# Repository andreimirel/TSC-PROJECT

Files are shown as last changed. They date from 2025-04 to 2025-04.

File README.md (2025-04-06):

# OpenBook E-Reader - TSC PROJECT

## General description
  The OpenBook E-Reader is an open-source e-reader device offering a distraction-free reading experience with physical buttons and a minimalist interface. It features environmental sensors that provide real-time environmental data, a sustainable design, and extended battery life of at least one week. The device boasts a large e-paper display, slim ergonomic design, and USB-C connectivity for charging and data transfer. OpenBook supports wireless ebook downloads and emphasizes customizable hardware and software for the tech-savvy reader. It aims to serve avid readers who value open-source technology, customization options, and environmental awareness.

## Block Diagram
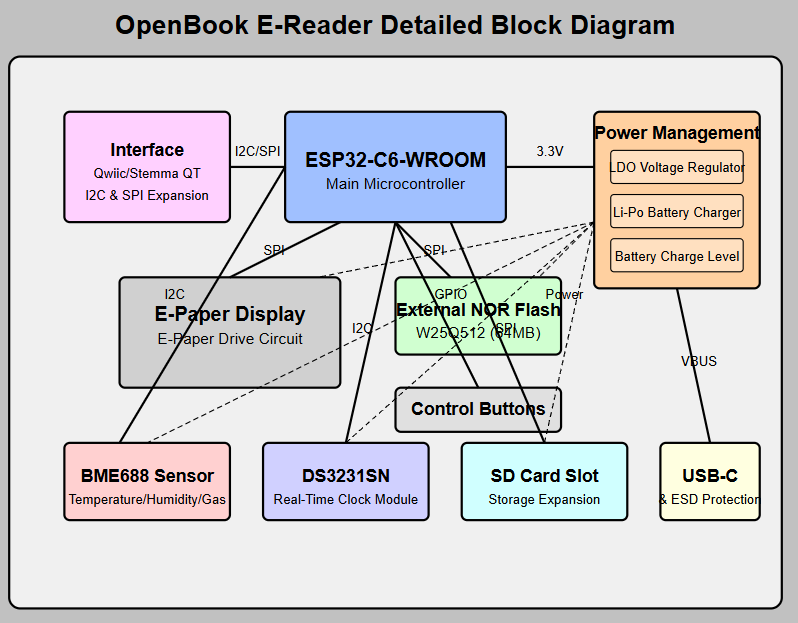
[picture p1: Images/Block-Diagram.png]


## Bill of Materials

| Qty | Value | Description | Manufacturer Part # | Mouser Link |
|-----|---|---|---|---|
| 1 | - | ESP32-C6 Module | ESP32-C6-WROOM-1-N8 | [Datasheet](https://www.mouser.co.uk/datasheet/2/891/Espressif_ESP32_C6_WROOM_1__Datasheet_V0_1_PRELIMI-3239987.pdf) |
| 1 | - | Environmental Sensor | BME688 | [Datasheet](https://www.mouser.co.uk/datasheet/2/783/bst_bme688_fl000-2307034.pdf) |
| 1 | - | Real Time Clock | DS3231SN# | [Datasheet](https://www.mouser.co.uk/datasheet/2/609/DS3231-3421123.pdf) |
| 1 | - | MicroSD Card Socket | 112A-TAAR-R03 ATTEND | [Datasheet](https://www.attend.com.tw/data/download/file/112A-TAAR-R03.rar) |
| 1 | - | USB Type-C Connector | USB4110-GF-A | [Datasheet](https://www.mouser.co.uk/datasheet/2/837/GCT_USB4110_Product_Drawing___20k_cycles-3455479.pdf) |
| 1 | - | FFC Connector | FH34SRJ-24S-0.5SH | [Datasheet](https://www.mouser.co.uk/datasheet/2/185/FH34SRJ_24S_0_5SH_99__CL0580_1255_6_99_2DDrawing_0-1615044.pdf) |
| 1 | - | Qwiic Connector | QWIIC_RIGHT_ANGLE | [Datasheet](https://www.mouser.co.uk/datasheet/2/813/Qwiic_Connector_Datasheet-1223982.pdf) |
| 1 | - | Li-Ion Charge Controller | MCP73831 | [Datasheet](https://www.mouser.co.uk/datasheet/2/268/MCP73831_Family_Data_Sheet_DS20001984H-3441711.pdf) |
| 1 | - | LDO Regulator | XC6220A331MR-G | [Datasheet](https://www.mouser.co.uk/datasheet/2/760/xc6220-3371556.pdf) |
| 1 | - | Fuel Gauge IC | MAX17048G+T10 | [Datasheet](https://www.mouser.co.uk/datasheet/2/609/MAX17048_MAX17049-3469099.pdf) |
| 1 | - | Voltage Detector | BD5229G-TR | [Datasheet](https://fscdn.rohm.com/en/products/databook/datasheet/ic/power/voltage_detector/bd52xxg-e.pdf) |
| 2 | 20V/4.2A | P-Channel MOSFET | DMG2305UX-7 | [Datasheet](https://www.diodes.com/assets/Datasheets/DMG2305UX.pdf) |
| 1 | - | N-Channel MOSFET | SI1308EDL-T1-GE3 | [Datasheet](https://www.vishay.com/doc?63399) |
| 15 | 10kΩ | Resistor | RR0402 | [Datasheet](https://www.mouser.com/ds/2/447/PYu-RC0402_51_RoHS_L_6_r-8721.pdf) |
| 8 | 100nF | Capacitor | CC0402 | [Datasheet](https://eu.mouser.com/datasheet/2/40/cx5r_KGM-3223198.pdf) |
| 10 | 1µF/50V | Capacitor | CC0402 | [Datasheet](https://eu.mouser.com/datasheet/2/40/cx5r_KGM-3223198.pdf) |
| 5 | 4.7µF | Capacitor | CC0402 | [Datasheet](https://eu.mouser.com/datasheet/2/40/cx5r_KGM-3223198.pdf) |
| 3 | - | Schottky Diode | MBR0530 | [Datasheet](https://www.onsemi.com/PowerSolutions/product.do?id=MBR0530T3G) |
| 6 | - | TVS Diode | PGB1010603MR | [Datasheet](https://www.littelfuse.com/assetdocs/pulseguard-esd-suppressors-pgb1-datasheet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) |
| 1 | 100µF | Polarized Capacitor | CPOL-EUCT3528 | [Datasheet](https://www.mouser.co.uk/datasheet/2/396/mlcc02_e-1307760.pdf) |
| 1 | - | Inductor | 744043680 | [Datasheet](https://www.we-online.com/components/products/datasheet/744043680.pdf) |
| 1 | - | ESD Protection Diode | USBLC6-2SC6Y | [Datasheet](https://www.mouser.co.uk/datasheet/2/389/usblc6_2sc6y-1852505.pdf) |
| 2 | - | Schottky Diode | SD0805S020S1R0 | [Datasheet](https://www.mouser.co.uk/datasheet/2/40/schottky-3165252.pdf) |
| 1 | - | Supercapacitor | CPH3225A | [Datasheet](https://www.mouser.co.uk/datasheet/2/360/Seiko_Instruments_MicroBattery_E_20230330_2024Jan_-3561061.pdf) |
| 1 | - | Varistor | ESP32C6_VARISTOR_CT | [Datasheet](https://www.mouser.co.uk/datasheet/2/358/typ_PFMF-1275918.pdf) |
| 17 | - | Test Points | TPTP20R | [Datasheet](https://www.mouser.co.uk/datasheet/2/215/5265_5269-2935484.pdf) |
| 1 | - | Solder Jumper | SJ | [Datasheet](https://www.mouser.co.uk/datasheet/2/210/ASC_WR-3314721.pdf) |
| 1 | - | LED (Green) | ADAFRUIT_LEDCHIP-LED0603 | [Specs](https://www.3dcontentcentral.com/secure/download-model.aspx?catalogid=9481&id=681976) |
| 3 | - | Custom Buttons | BUTTON_CUSYOMV1 | - |

## Core Hardware Modules

### 1. Processing Unit
- **ESP32-C6-WROOM-1-N8**  
  - **Key Features**:
    - 160MHz RISC-V single-core processor
    - 512KB SRAM + 8MB external flash
    - Wi-Fi 6 (802.11ax) and Bluetooth 5 LE
    - Ultra-low-power modes (<5µA deep sleep)
  - **Functions**:
    - Manages all peripheral communication
    - Handles e-book rendering and UI operations
    - Processes environmental sensor data
    - Manages power states and battery charging

### 2. Display System
- **7.5" E-Paper Display (WSH-13187)**
  - **Specifications**:
    - 800×480 resolution, 8:1 contrast ratio
    - SPI interface (4-wire) @ 10MHz max
    - Partial refresh (<0.5s), full refresh (<1s)
    - 170° viewing angle
  - **Power Management**:
    - 0W power consumption when static
    - 120mW during refresh (active)

### 3. Environmental Sensing
- **BME688 Integrated Sensor**
  - **Measurement Capabilities**:
    - Temperature: ±1°C accuracy (0-65°C)
    - Humidity: ±3% RH (20-80% RH)
    - Pressure: ±1 hPa (300-1100 hPa)
    - Air Quality: VOC and eCO2 detection
  - **Interface**:
    - I2C @ 400kHz
    - 30s warm-up time for accurate readings
  - **Power Consumption**:
    - 2mA during active measurement
    - 0.5µA in sleep mode

### 4. Power Management System
| Component | Function | Specifications |
|---|---|---|
| **2500mAh LiPo Battery** | Primary power source | 3.7V nominal, 2C discharge rate |
| **MCP73831** | Battery charging | 500mA max charge current, 4.2V regulation |
| **MAX17048** | Fuel gauge | ±1% voltage accuracy, I2C interface |
| **XC6220A331MR-G** | Voltage regulator | 3.3V @ 300mA, 50µA quiescent current |

### 5. User Interface Components
- **Tactile Buttons (3x)**
  - Panasonic EVQ-Q2A03W switches
  - 1M cycle lifespan
  - Hardware-debounced (RC filters)
- **LED Indicators**:
  - Charging status (red/green)
  - System activity (blue)

### 6. Connectivity
- **USB-C Port (Amphenol 12401641E4R)**
  - USB 2.0 Full Speed (12Mbps)
  - 5V/1A charging
  - ESD protection (USBLC6-2SC6Y)
- **Wi-Fi 6**:
  - 20MHz channel bandwidth
  - WPA3 security support
  - OTA update capability

### 7. Memory & Storage
| Component | Type | Capacity | Interface |
|---|---|---|---|
| **W25Q512JVEIQ** | SPI Flash | 512Mb (64MB) | Quad-SPI @ 133MHz |
| **MicroSD Slot** | Expandable | Up to 1TB | SPI @ 25MHz |

## ESP32-C6 Pins

| ESP32-C6 Pin | Component / Function  | Description and Reason for Use |
|---|---|---|
| IO1 (SDA) | I2C Bus | Used for communication with the BME688 sensor, battery fuel gauge IC (MAX17048), and RTC (DS3231). I²C enables multiple devices on one bus. |
| IO2 (SCL) | I2C Clock | Provides the clock signal for the I²C bus, synchronizing data transfer between the ESP32-C6 and connected I²C devices. |
| IO5 (MISO) | SPI (E-Paper) | Master In Slave Out for the SPI interface with the E-Paper display; receives data from the display to the ESP32-C6. |
| IO6 (MOSI) | SPI (E-Paper) | Master Out Slave In for the SPI interface with the E-Paper display; sends data from the ESP32-C6 to the display. |
| IO7 (SCK) | SPI Clock (E-Paper) | Provides the clock signal for the SPI interface with the E-Paper display, synchronizing data transfer. |
| IO8 (CS) | Chip Select (E-Paper) | Selects the E-Paper display for SPI communication, allowing communication with a single SPI device at a time. |
| IO9 | E-Paper DC | Data/Command control for the E-Paper display, indicating whether the transmitted data is command instructions or display data. |
| IO10 | E-Paper RST | Reset pin for the E-Paper display, used to initialize or reset the display. |
| IO11 | E-Paper BUSY | Busy status pin for the E-Paper display, indicating if the display is occupied and cannot receive new commands. |
| IO12 | BUTTON_BOOT | Button to enter programming/bootload mode. |
| IO13 | BUTTON_RESET | Button for hardware reset of the ESP32-C6. |
| IO14 | BUTTON_USER | User-defined button for application interactions. |
| IO15 | MAX17048 ALERT | Alert pin from the battery fuel gauge IC, signaling critical battery conditions. |
| GPIO16/TXD0 | USB D+ | Positive data line for the USB interface. |
| GPIO17/RXD0 | USB D- | Negative data line for the USB interface. |
| IO18 | STATUS_LED | Controls the status LED for visual indication of the device state. |
| IO19 | SD Card CS | Chip select for the SD card on the SPI interface. |
| IO20 | SD Card MISO | Master In Slave Out for the SPI interface with the SD card; receives data from the SD card. |
| IO21 | SD Card MOSI | Master Out Slave In for the SPI interface with the SD card; sends data to the SD card. |
| IO4 | SD Card CLK | SPI clock for the SD card, synchronizing data transfer. |

###  Additional Details - ESP32-C6 Pins
  
  ####   I2C Interface
      The GPIO1 (SDA) and GPIO2 (SCL) pins are used for the I²C bus, connecting the ESP32-C6 to:
        - **BME688 Sensor:** For reading temperature, humidity, pressure, and air quality data.
        - **MAX17048:** For monitoring battery level.
        - **DS3231:** For real-time clock (RTC) functionality.
    
  ####   SPI Interface
      The GPIO5, GPIO6, GPIO7, and GPIO8 pins are dedicated to the SPI interface with the E-Paper display. This interface requires:
        - **MISO (GPIO5):** Receives data from the display.
        - **MOSI (GPIO6):** Transmits data to the display.
        - **SCK (GPIO7):** Synchronizes the data transfer.
        - **CS (GPIO8):** Selects the E-Paper display for communication.
    
  ####  User Buttons
      The GPIO12, GPIO13, and GPIO14 pins are connected to the user control buttons:
        - **GPIO12 (BUTTON_BOOT):** Enters programming/bootload mode.
        - **GPIO13 (BUTTON_RESET):** Resets the ESP32-C6.
        - **GPIO14 (BUTTON_USER):** Allows user-defined interactions.
    
  ####  USB
      GPIO16 and GPIO17 are used for the USB interface, facilitating data transfer and charging.
    
  ####  SD Card
      The GPIO19, GPIO20, GPIO21, and GPIO4 pins are used for the SPI interface with the SD card, enabling data storage and access.

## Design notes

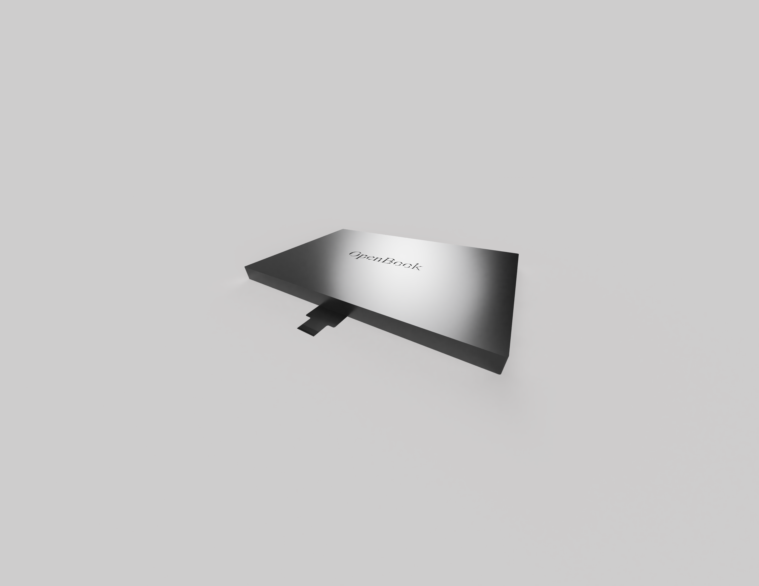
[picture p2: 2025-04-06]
Images/OpenBook_E-Book_Reader_2025-Apr-06_10-16-19AM-000_CustomizedView25883885497_png.png

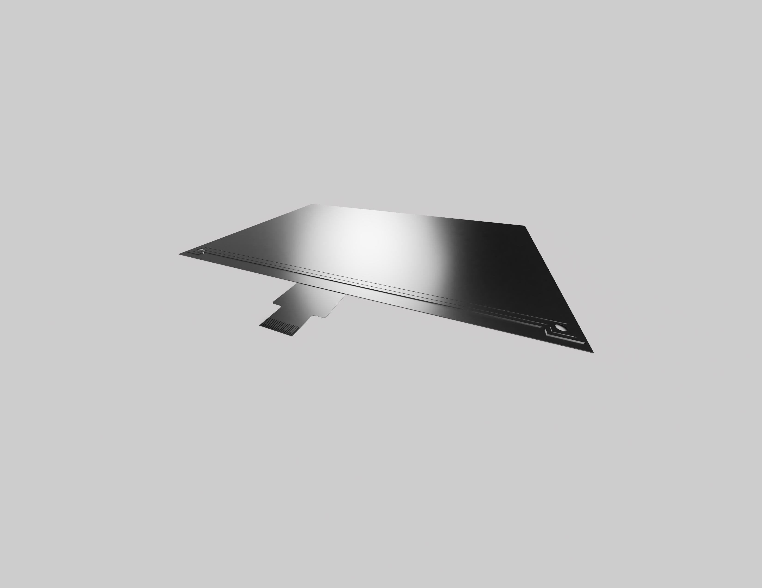
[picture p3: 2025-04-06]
Images/OpenBook_E-Book_Reader_2025-Apr-06_10-19-33AM-000_CustomizedView18438601844_png.png

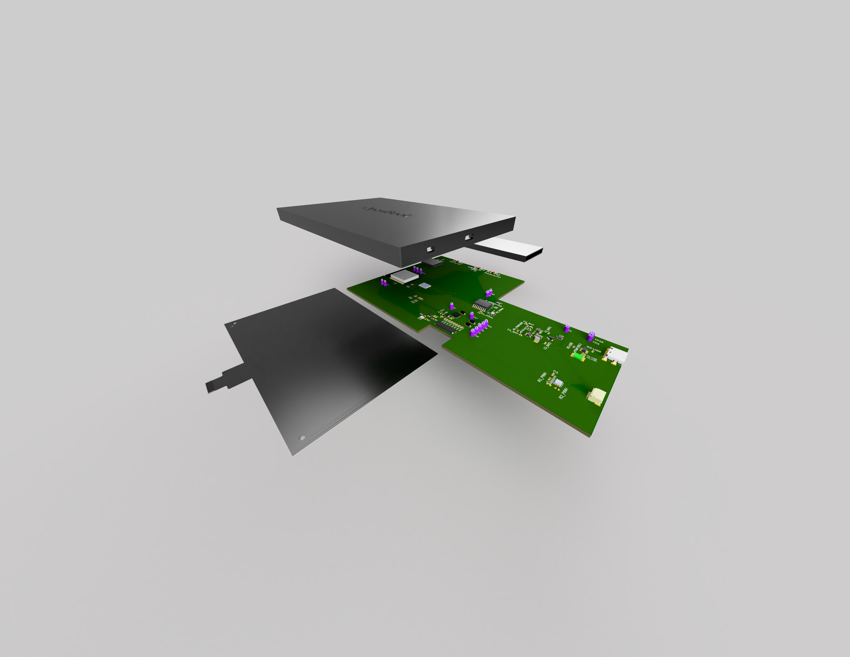
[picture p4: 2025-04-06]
Images/OpenBook_E-Book_Reader_2025-Apr-06_10-23-46AM-000_CustomizedView27298161075_png.png

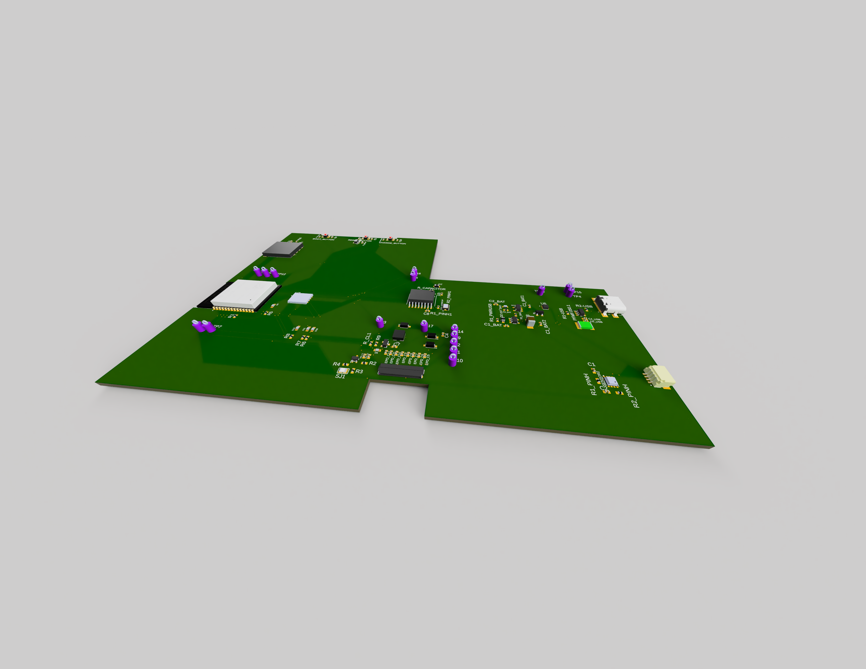
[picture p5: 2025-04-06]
Images/OpenBook_E-Book_Reader_2025-Apr-06_10-17-53AM-000_CustomizedView38768882471_png.png

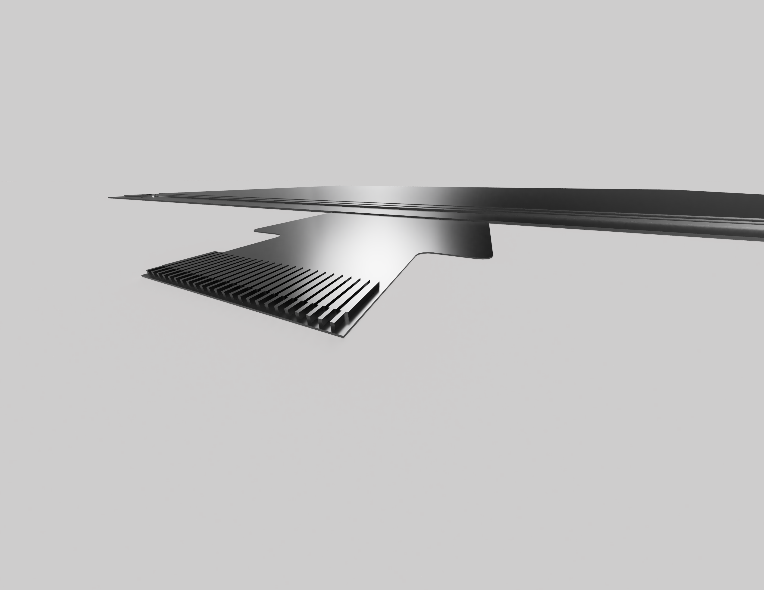
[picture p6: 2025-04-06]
Images/OpenBook_E-Book_Reader_2025-Apr-06_10-20-03AM-000_CustomizedView36715459351_png.png

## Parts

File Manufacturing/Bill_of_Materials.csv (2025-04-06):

Qty | Value | Device | Package | Parts | Description | ARROW_PART_NUMBER | ARROW_PRICE-STOCK | AVAILABILITY | CENTROID_NOT_SPECIFIED | CHECK_PRICES | COPYRIGHT | DATASHEET | DESCRIPTION | DIGIKEY_DESCRIPTION | DIGIKEY_PART_NUMBER | HEIGHT | LEAD_FREE | MANUFACTURER_NAME | MANUFACTURER_PART_NUMBER | MF | MFR_NAME | MOUSER_PART_NUMBER | MOUSER_PRICE-STOCK | MOUSER_TESTING_PART_NUMBER | MOUSER_TESTING_PRICE-STOCK | MP | MPN | PACKAGE | POPULARITY | PREFIX | PRICE | PROD_ID | PURCHASE-URL | ROHS | SNAPEDA_LINK | SPICEMODEL | SPICEPREFIX | TEMPERATURE_RANGE_HIGH | TEMPERATURE_RANGE_LOW | TP_SIGNAL_NAME | VALUE
1 |  | ADAFRUIT_LEDCHIP-LED0603 | ADAFRUIT_CHIP-LED0603 | CHG_LED | LED
3 |  | BUTTON_CUSYOMV1 | MYBUTTON | BOOT_BUTTON, CHANGE_BUTTON, RESET_BUTTON
1 |  | ESP32C6_VARISTORCN1812 | ESP32C6_VARISTOR_CT/CN1812 | PFMF.050.1 | VARISTOR |  |  |  |  |  |  |  |  |  |  |  |  |  |  |  |  |  |  |  |  |  |  |  | 0
1 |  | ESP32_WROVER_SPARKFUN-IC-POWER_MCP73831 | ESP32_WROVER_SPARKFUN-IC-POWER_SOT23-5 | MCP73831 | MCP73831T Li-Ion, Li-Pol Controller |  |  |  |  |  |  |  |  |  |  |  |  |  |  |  |  |  |  |  |  |  |  |  |  |  |  | IC-09995
1 |  | SAMACSYS_PARTS_USB4110-GF-A | SAMACSYS_PARTS_USB4110GFA | J2 | CONN USB 2.0 TYPE-C R/A SMT |  |  |  |  |  |  |  | CONN USB 2.0 TYPE-C R/A SMT |  |  | 3.26mm |  | GCT (GLOBAL CONNECTOR TECHNOLOGY) | USB4110-GF-A |  |  | 640-USB4110-GF-A | https://www.mouser.co.uk/ProductDetail/GCT/USB4110-GF-A?qs=KUoIvG%2F9IlYiZvIXQjyJeA%3D%3D
1 |  | SJ | SJ | SJ1 | SMD solder JUMPER |  |  |  |  |  |  |  |  |  |  |  |  |  |  |  |  |  |  |  |  |  |  |  | 3
1 | 0.47 | ESP32_WROVER_EAGLE-LTSPICE_RR0402 | ESP32_WROVER_EAGLE-LTSPICE_R0402 | R3 | RESISTOR, European symbol |  |  |  |  |  |  |  |  |  |  |  |  |  |  |  |  |  |  |  |  |  |  |  |  |  |  |  |  |  |  | NONE | R
1 | 100k | ESP32_WROVER_EAGLE-LTSPICE_RR0402 | ESP32_WROVER_EAGLE-LTSPICE_R0402 | R1_PWRUSB | RESISTOR, European symbol |  |  |  |  |  |  |  |  |  |  |  |  |  |  |  |  |  |  |  |  |  |  |  |  |  |  |  |  |  |  | NONE | R
8 | 100nF | EAGLE-LTSPICE_CC0402 | EAGLE-LTSPICE_C0402 | C1, C2, C4_USB, C6, C8, C9, C10\, C_DELAY | CAPACITOR, European symbol |  |  |  |  |  |  |  |  |  |  |  |  |  |  |  |  |  |  |  |  |  |  |  |  |  |  |  |  |  |  | NONE | C
1 | 100uF | RCL_CPOL-EUCT3528 | RCL_CT3528 | C3 | POLARIZED CAPACITOR, European symbol |  |  |  |  |  |  |  |  |  |  |  |  |  |  |  |  |  |  |  |  |  |  |  | 0 |  |  |  |  |  |  |  | C
15 | 10K | ESP32_WROVER_EAGLE-LTSPICE_RR0402 | ESP32_WROVER_EAGLE-LTSPICE_R0402 | R1, R1_PINH, R1_PINH1, R2_PINH, R2_PINH1, R5, R6, R7, R8, R9, R10, R_BUTTON, R_CHANGE, R_CL1, R_RESET | RESISTOR, European symbol |  |  |  |  |  |  |  |  |  |  |  |  |  |  |  |  |  |  |  |  |  |  |  |  |  |  |  |  |  |  | NONE | R
1 | 10k | ESP32_WROVER_EAGLE-LTSPICE_RR0402 | ESP32_WROVER_EAGLE-LTSPICE_R0402 | R4 | RESISTOR, European symbol |  |  |  |  |  |  |  |  |  |  |  |  |  |  |  |  |  |  |  |  |  |  |  |  |  |  |  |  |  |  | NONE | R
1 | 10uF | EAGLE-LTSPICE_CC0402 | EAGLE-LTSPICE_C0402 | C7 | CAPACITOR, European symbol |  |  |  |  |  |  |  |  |  |  |  |  |  |  |  |  |  |  |  |  |  |  |  |  |  |  |  |  |  |  | NONE | C
1 | 112A-TAAR-R03_ATTEND | 112A-TAAR-R03_ATTEND | 112ATAARR03ATTEND | U2 | Micro SD Card Socket, Push-Push Type, Top Mount, SMT, H=1.83mm, 10u |  |  |  |  |  |  |  | Micro SD Card Socket | Push-Push Type | Top Mount | SMT | H=1.83mm | 10u |  |  | 1.9mm |  | ATTEND | 112A-TAAR-R03 ATTEND
1 | 15 | ESP32_WROVER_EAGLE-LTSPICE_RR0402 | ESP32_WROVER_EAGLE-LTSPICE_R0402 | R_CAPACITOR | RESISTOR, European symbol |  |  |  |  |  |  |  |  |  |  |  |  |  |  |  |  |  |  |  |  |  |  |  |  |  |  |  |  |  |  | NONE | R
1 | 1uF | EAGLE-LTSPICE_CC0402 | EAGLE-LTSPICE_C0402 | C5 | CAPACITOR, European symbol |  |  |  |  |  |  |  |  |  |  |  |  |  |  |  |  |  |  |  |  |  |  |  |  |  |  |  |  |  |  | NONE | C
10 | 1uF/50V | EAGLE-LTSPICE_CC0402 | EAGLE-LTSPICE_C0402 | EPD_C1, EPD_C2, EPD_C5, EPD_C6, EPD_C7, EPD_C8, EPD_C9, EPD_C10, EPD_C11, EPD_C12 | CAPACITOR, European symbol |  |  |  |  |  |  |  |  |  |  |  |  |  |  |  |  |  |  |  |  |  |  |  |  |  |  |  |  |  |  | NONE | C
1 | 2.2 | ESP32_WROVER_EAGLE-LTSPICE_RR0402 | ESP32_WROVER_EAGLE-LTSPICE_R0402 | R2 | RESISTOR, European symbol |  |  |  |  |  |  |  |  |  |  |  |  |  |  |  |  |  |  |  |  |  |  |  |  |  |  |  |  |  |  | NONE | R
1 | 200 | ESP32_WROVER_EAGLE-LTSPICE_RR0402 | ESP32_WROVER_EAGLE-LTSPICE_R0402 | R1_BAT | RESISTOR, European symbol |  |  |  |  |  |  |  |  |  |  |  |  |  |  |  |  |  |  |  |  |  |  |  |  |  |  |  |  |  |  | NONE | R
2 | 20V/4.2A/52mΩ/1.4W | ESP32_WROVER_SPARKFUN-DISCRETESEMI_MOSFET_PCH-DMG2305UX-7 | ESP32_WROVER_SPARKFUN-DISCRETESEMI_SOT23-3 | Q1, Q2 | P-channel MOSFETs |  |  |  |  |  |  |  |  |  |  |  |  |  |  |  |  |  |  |  |  |  |  |  |  |  |  | TRAN-14388 |  |  |  |  |  |  |  |  | 20V/4.2A/52mΩ/1.4W
1 | 2K | ESP32_WROVER_EAGLE-LTSPICE_RR0402 | ESP32_WROVER_EAGLE-LTSPICE_R0402 | R2_BAT | RESISTOR, European symbol |  |  |  |  |  |  |  |  |  |  |  |  |  |  |  |  |  |  |  |  |  |  |  |  |  |  |  |  |  |  | NONE | R
5 | 4.7uF | EAGLE-LTSPICE_CC0402 | EAGLE-LTSPICE_C0402 | C1_BAT, C1_BAT1, C1_BAT2, C2_BAT, C5_USB | CAPACITOR, European symbol |  |  |  |  |  |  |  |  |  |  |  |  |  |  |  |  |  |  |  |  |  |  |  |  |  |  |  |  |  |  | NONE | C
1 | 4.7uF/25V | EAGLE-LTSPICE_CC0402 | EAGLE-LTSPICE_C0402 | C4 | CAPACITOR, European symbol |  |  |  |  |  |  |  |  |  |  |  |  |  |  |  |  |  |  |  |  |  |  |  |  |  |  |  |  |  |  | NONE | C
2 | 5k1 | ESP32_WROVER_EAGLE-LTSPICE_RR0402 | ESP32_WROVER_EAGLE-LTSPICE_R0402 | R1-USB, R2-USB | RESISTOR, European symbol |  |  |  |  |  |  |  |  |  |  |  |  |  |  |  |  |  |  |  |  |  |  |  |  |  |  |  |  |  |  | NONE | R
1 | 744043680IND_4828-WE-TPC_WRE | 744043680IND_4828-WE-TPC_WRE | IND_4828-WE-TPC_WRE | L1 |  |  |  |  |  |  | Copyright (C) 2024 Ultra Librarian. All rights reserved. |  |  |  |  |  |  |  | 744043680 |  | Wurth Electronics
1 | BD5229G-TR | BD5229G-TR | SOT95P280X125-5N | IC1 | Voltage Detector with Adjustable Delay Time: CMOS processes are utilized to develop high precision, low current consumption CMOS reset ICs that allow arbitrary setting of the delay time. The extensive lineup includes both Nch Open Drain and CMOS output types in a wide range of detection voltages (from 2.3V to 6.0V, in 0.1V steps), enabling selection of the ideal solution based on customer requirements. In addition, the entire series is of course both lead-free and RoHS-compliant. |  |  |  |  |  |  |  | Voltage Detector with Adjustable Delay Time: CMOS processes are utilized to develop high precision | low current consumption CMOS reset ICs that allow arbitrary setting of the delay time. The extensive lineup includes both Nch Open Drain and CMOS output types in a wide range of detection voltages (from 2.3V to 6.0V | in 0.1V steps) | enabling selection of the ideal solution based on customer requirements. In addition | the entire series is of course both lead-free and RoHS-compliant. |  |  | 1.25mm |  | ROHM Semiconductor | BD5229G-TR |  |  | 755-BD5229G-TR | https://www.mouser.co.uk/ProductDetail/ROHM-Semiconductor/BD5229G-TR?qs=4kLU8WoGk0vvnhrrYwdszw%3D%3D
1 | BME688 | ESP32_WROVER_BME680_BME680 | ESP32_WROVER_BME680_PSON80P300X300X100-8N | SENSOR2 | Integrated Environmental Unit |  |  | Unavailable |  |  |  |  | Integrated Environmental Unit |  |  |  |  |  |  | Bosch Sensortec |  |  |  |  |  | BME680 |  | LGA-8 Bosch Tools |  |  | None
1 | CPH3225A | CPH3225A | CAPCP3225X100N | C10_SUPERCAP | Cap 0.011F 3.3V 1210 Flat Check availability |  |  | Not in stock |  | https://www.snapeda.com/parts/CPH3225A/Seiko+Instruments/view-part/?ref=eda |  |  | 11 mF (EDLC) Supercapacitor 3.3 V 1210 (3225 Metric) - - |  |  |  |  |  |  | Seiko Instruments |  |  |  |  |  | CPH3225A |  | 1210 Seiko |  |  | None |  | https://www.snapeda.com/api/url_track_click_mouser/?unipart_id=562593&manufacturer=Seiko Instruments&part_name=CPH3225A&search_term=None |  | https://www.snapeda.com/parts/CPH3225A/Seiko+Instruments/view-part/?ref=snap
1 | DS3231SN# | DS3231SN# | SOIC127P1032X265-16N | U3 | Real Time Clock Serial 16-Pin SOIC W T/R Check availability |  |  | In Stock |  | https://www.snapeda.com/parts/DS3231SN%23/Analog+Devices/view-part/?ref=eda |  |  | Extremely Accurate I²C-Integrated RTC/TCXO/Crystal |  |  |  |  |  |  | Analog Devices |  |  |  |  |  | DS3231SN# |  | SOIC-16 Maxim |  |  | None |  | https://www.snapeda.com/api/url_track_click_mouser/?unipart_id=99048&manufacturer=Analog Devices&part_name=DS3231SN#&search_term=None |  | https://www.snapeda.com/parts/DS3231SN%23/Analog+Devices/view-part/?ref=snap
1 | ESP32-C6-WROOM-1-N8 | ESP32-C6-WROOM-1-N8 | XCVR_ESP32-C6-WROOM-1-N8 | U1 | Check availability |  |  | In Stock |  | https://www.snapeda.com/parts/ESP32-C6-WROOM-1-N8/Espressif+Systems/view-part/?ref=eda |  |  | Multiprotocol Modules ESP32-C6 module | Wi-Fi 6 in 2.4 GHz band | Bluetooth 5 | Zigbee 3.0 and Thread. ESP34-WROOM Compatible - ENGINEERING SAMPLE |  |  |  |  |  |  | Espressif Systems |  |  |  |  |  | ESP32-C6-WROOM-1-N8 |  | None |  |  | None |  |  |  | https://www.snapeda.com/parts/ESP32-C6-WROOM-1-N8/Espressif+Systems/view-part/?ref=snap
2 | ESP32_WROVER_AVX---SD0805S020S1R0_AVX_SD0805S020S1R0_0_0AVX_SD0805S020S1R0_0_0 | ESP32_WROVER_AVX---SD0805S020S1R0_AVX_SD0805S020S1R0_0_0AVX_SD0805S020S1R0_0_0 | ESP32_WROVER_AVX---SD0805S020S1R0_AVX_SD0805S020S1R0_0 | D2, D7 | Schottky Barrier Rectifier Diode |  |  |  | No |  |  | http://datasheets.avx.com/schottky.pdf |  | DIODE SCHOTTKY 20V 1A 0805 | 478-7800-1-ND |  | yes |  |  | AVX |  | 581-SD0805S020S1R0 |  |  |  |  |  | 0805 (2012 metric) |  | D |  |  |  | yes |  |  |  | +125°C | -55°C
1 | FH34SRJ-24S-0.5SH_99_ | FH34SRJ-24S-0.5SH_99_ | FH34SRJ24S05SH99 | J1 | (0.50mm) Surface Mount, Right Angle |  |  |  |  |  |  |  | 24 Position FFC | FPC Connector Contacts | (0.50mm) Surface Mount | Right Angle |  |  | 1.1mm |  | Hirose | FH34SRJ-24S-0.5SH(99) |  |  | 798-FH34SRJ24S05SH99 | https://www.mouser.co.uk/ProductDetail/Hirose-Connector/FH34SRJ-24S-0.5SH99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
1 | MAX17048G+T10 | MAX17048G+T10 | SON50P200X200X80-9N | U5 | Check availability |  |  | In Stock |  | https://www.snapeda.com/parts/MAX17048G+T10/Analog+Devices/view-part/?ref=eda |  |  | 3µA 1-Cell/2-Cell Fuel Gauge with ModelGauge |  |  |  |  |  |  | Analog Devices |  |  |  |  |  | MAX17048G+T10 |  | TDFN-8 Maxim |  |  | None |  | https://www.snapeda.com/api/url_track_click_mouser/?unipart_id=329239&manufacturer=Analog Devices&part_name=MAX17048G+T10&search_term=None |  | https://www.snapeda.com/parts/MAX17048G+T10/Analog+Devices/view-part/?ref=snap
3 | MBR0530 | MBR0530 | SOD3716X135N | D3, D4, D5 | ON SEMICONDUCTOR - MBR0530 - DIODE, SCHOTTKY, 0.5A, 30V, SOD-123 |  |  | In Stock |  | https://www.snapeda.com/parts/MBR0530/Onsemi/view-part/?ref=eda |  |  | Diode Schottky 30 V 500mA Surface Mount SOD-123 |  |  |  |  |  |  | ON Semiconductor |  |  |  |  |  | MBR0530 |  | SOD-123-2 ON Semiconductor |  |  | None |  | https://www.snapeda.com/api/url_track_click_mouser/?unipart_id=179458&manufacturer=ON Semiconductor&part_name=MBR0530&search_term=None |  | https://www.snapeda.com/parts/MBR0530/Onsemi/view-part/?ref=snap
6 | PGB1010603MR | PGB1010603MR | DIOC1608X36N | D6, D8, D9, D10, D11, D12 | Check availability |  |  | In Stock |  | https://www.snapeda.com/parts/PGB1010603MR/Littelfuse/view-part/?ref=eda |  |  | 150V (Typ) Clamp - Ipp Tvs Diode Surface Mount 0603 (1608 Metric) |  |  |  |  |  |  | Littelfuse Inc. |  |  |  |  |  | PGB1010603MR |  | 0603 Littelfuse Inc. |  |  | None |  | https://www.snapeda.com/api/url_track_click_mouser/?unipart_id=5659453&manufacturer=Littelfuse Inc.&part_name=PGB1010603MR&search_term=None |  | https://www.snapeda.com/parts/PGB1010603MR/Littelfuse/view-part/?ref=snap
1 | QWIIC_RIGHT_ANGLE | QWIIC_CONNECTORJS-1MM | JST04_1MM_RA | J3 | SparkFun I2C Standard Qwiic Connector |  |  |  |  |  |  |  |  |  |  |  |  |  |  |  |  |  |  |  |  |  |  |  |  |  |  | CONN-13694 |  |  |  |  |  |  |  |  | QWIIC_RIGHT_ANGLE
1 | SI1308EDL-T1-GE3 | SI1308EDL-T1-GE3 | SOT65P210X110-3N | Q3 | MOSFET N-Ch 30V 1.5A TrenchFET SC70 Vishay Si1308EDL-T1-GE3 N-channel MOSFET Transistor, 1.5 A, 30 V, 3-Pin SC-70 |  |  | In Stock |  | https://www.snapeda.com/parts/SI1308EDL-T1-GE3/Vishay+Siliconix/view-part/?ref=eda |  |  | Si1308EDL-T1-GE3 N-channel MOSFET Transistor | 1.5 A | 30 V | 3-Pin SC-70 | Siliconix / Vishay SI1308EDL-T1-GE3 |  |  |  |  |  |  | Vishay Siliconix |  |  |  |  |  | SI1308EDL-T1-GE3 |  | SOT-323 Vishay Semiconductor |  |  | None |  | https://www.snapeda.com/api/url_track_click_mouser/?unipart_id=274603&manufacturer=Vishay Siliconix&part_name=SI1308EDL-T1-GE3&search_term=None |  | https://www.snapeda.com/parts/SI1308EDL-T1-GE3/Vishay+Siliconix/view-part/?ref=snap
17 | TPTP20R | TPTP20R | TP20R | TP1, TP2, TP3, TP4, TP5, TP6, TP7, TP8, TP9, TP10, TP11, TP12, TP13, TP14, TP15, TP16, TP17 | Test pad |  |  |  |  |  |  |  |  |  |  |  |  |  |  |  |  |  |  |  |  |  |  |  | 2
1 | USBLC6-2SC6Y | USBLC6-2SC6Y | SOT95P280X145-6N | D1 | Low Cap. ESD Protection Auto SOT-23-6 STMicroelectronics USBLC6-2SC6Y, Dual Uni-Directional TVS Diode Array, 6-Pin SOT-23 |  |  | In Stock |  | https://www.snapeda.com/parts/USBLC6-2SC6Y/STMicroelectronics/view-part/?ref=eda |  |  | 17V Clamp 5A (8/20µs) Ipp Tvs Diode Surface Mount SOT-23-6 |  |  |  |  |  |  | STMicroelectronics |  |  |  |  |  | USBLC6-2SC6Y |  | SOT-23-6 STMicroelectronics |  |  | None |  |  |  | https://www.snapeda.com/parts/USBLC6-2SC6Y/STMicroelectronics/view-part/?ref=snap
1 | W25Q512JVEIQ | W25Q512JVEIQ | SON127P600X800X80-9N | U7 | Check availability |  |  | In Stock |  | https://www.snapeda.com/parts/W25Q512JVEIQ/Winbond+Electronics/view-part/?ref=eda |  |  | FLASH - NOR Memory IC 512Mb (64M x 8) SPI - Quad I/O 133 MHz 8-WSON (8x6) |  |  |  |  |  |  | Winbond Electronics |  |  |  |  |  | W25Q512JVEIQ |  | Package |  |  | None |  |  |  | https://www.snapeda.com/parts/W25Q512JVEIQ/Winbond+Electronics/view-part/?ref=snap
1 | XC6220A331MR-G | XC6220A331MR-G | SOT95P280X120-5N | IC2 | LDO Voltage Regulators |  |  |  |  |  |  |  | LDO Voltage Regulators |  |  | 1.2mm |  | Torex | XC6220A331MR-G |  |  | 865-XC6220A331MR-G | https://www.mouser.co.uk/ProductDetail/Torex-Semiconductor/XC6220A331MR-G?qs=AsjdqWjXhJ8ZSWznL1J0gg%3D%3D

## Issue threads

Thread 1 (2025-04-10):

Schematic review

PXrotters, 2025-04-10:
## ERC Check:

✔️ **ERC check performed:** All reported issues are either tool quirks or false positives.

---

## Component Issues:

- **Missing values on components** (e.g., CHG_LED, SJ1, FRAME1): These appear intentional but could benefit from further clarification in the BOM.
- **POWER pins connected to non-default rails** (e.g., VDD to VBAT, VCC to 3V3): Cross-checked with datasheets and confirmed to be correct.

---

## Pin Verification:

✔️ **Pins verified and match datasheets.**
- Some component signal names differ slightly from the reference schematic, but they map correctly to the expected pins and behavior. These inconsistencies do not affect functionality but could be aligned in future versions for consistency.

---

## Component Footprints:

✔️ **Verified component footprints** — schematic symbol matches actual PCB package and pin count. All match datasheets.

---

Passive Components, Power Supply, Regulators, Decoupling, Errata, Signals, Analog, Clocks, Strap/init pins, External Interface Protection, Debugging / Reworkability, Thermal: all are ok and perform as expected.

## General Status:

**Passive Components, Power Supply, Regulators, Decoupling, Errata, Signals, Analog, Clocks, Strap/init pins, External Interface Protection, Debugging / Reworkability, Thermal:** All are **OK** and perform as expected.

**Suggested labels:** `documentation`, `enhancement`

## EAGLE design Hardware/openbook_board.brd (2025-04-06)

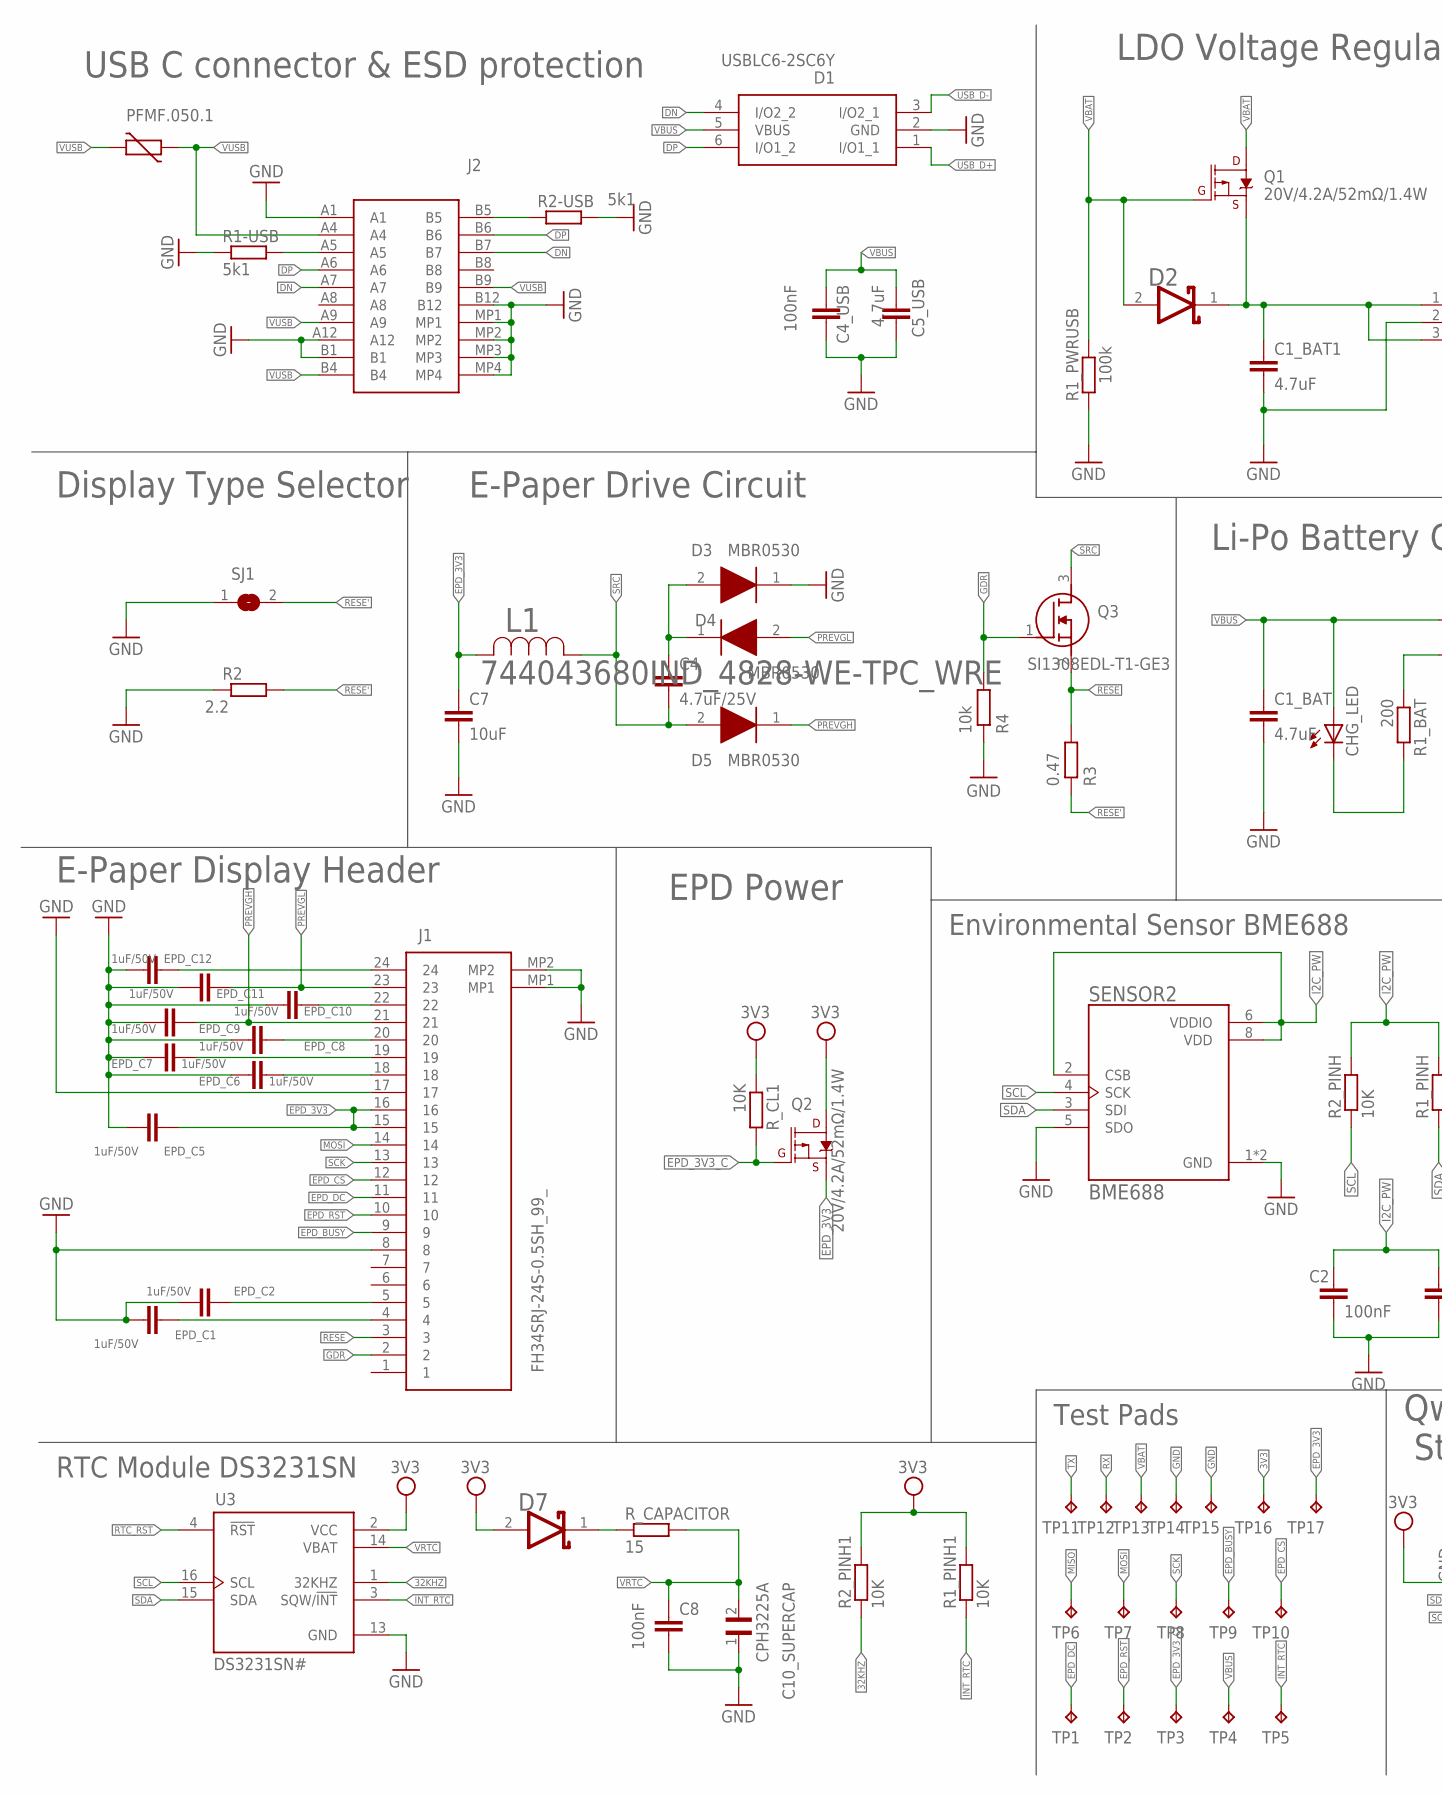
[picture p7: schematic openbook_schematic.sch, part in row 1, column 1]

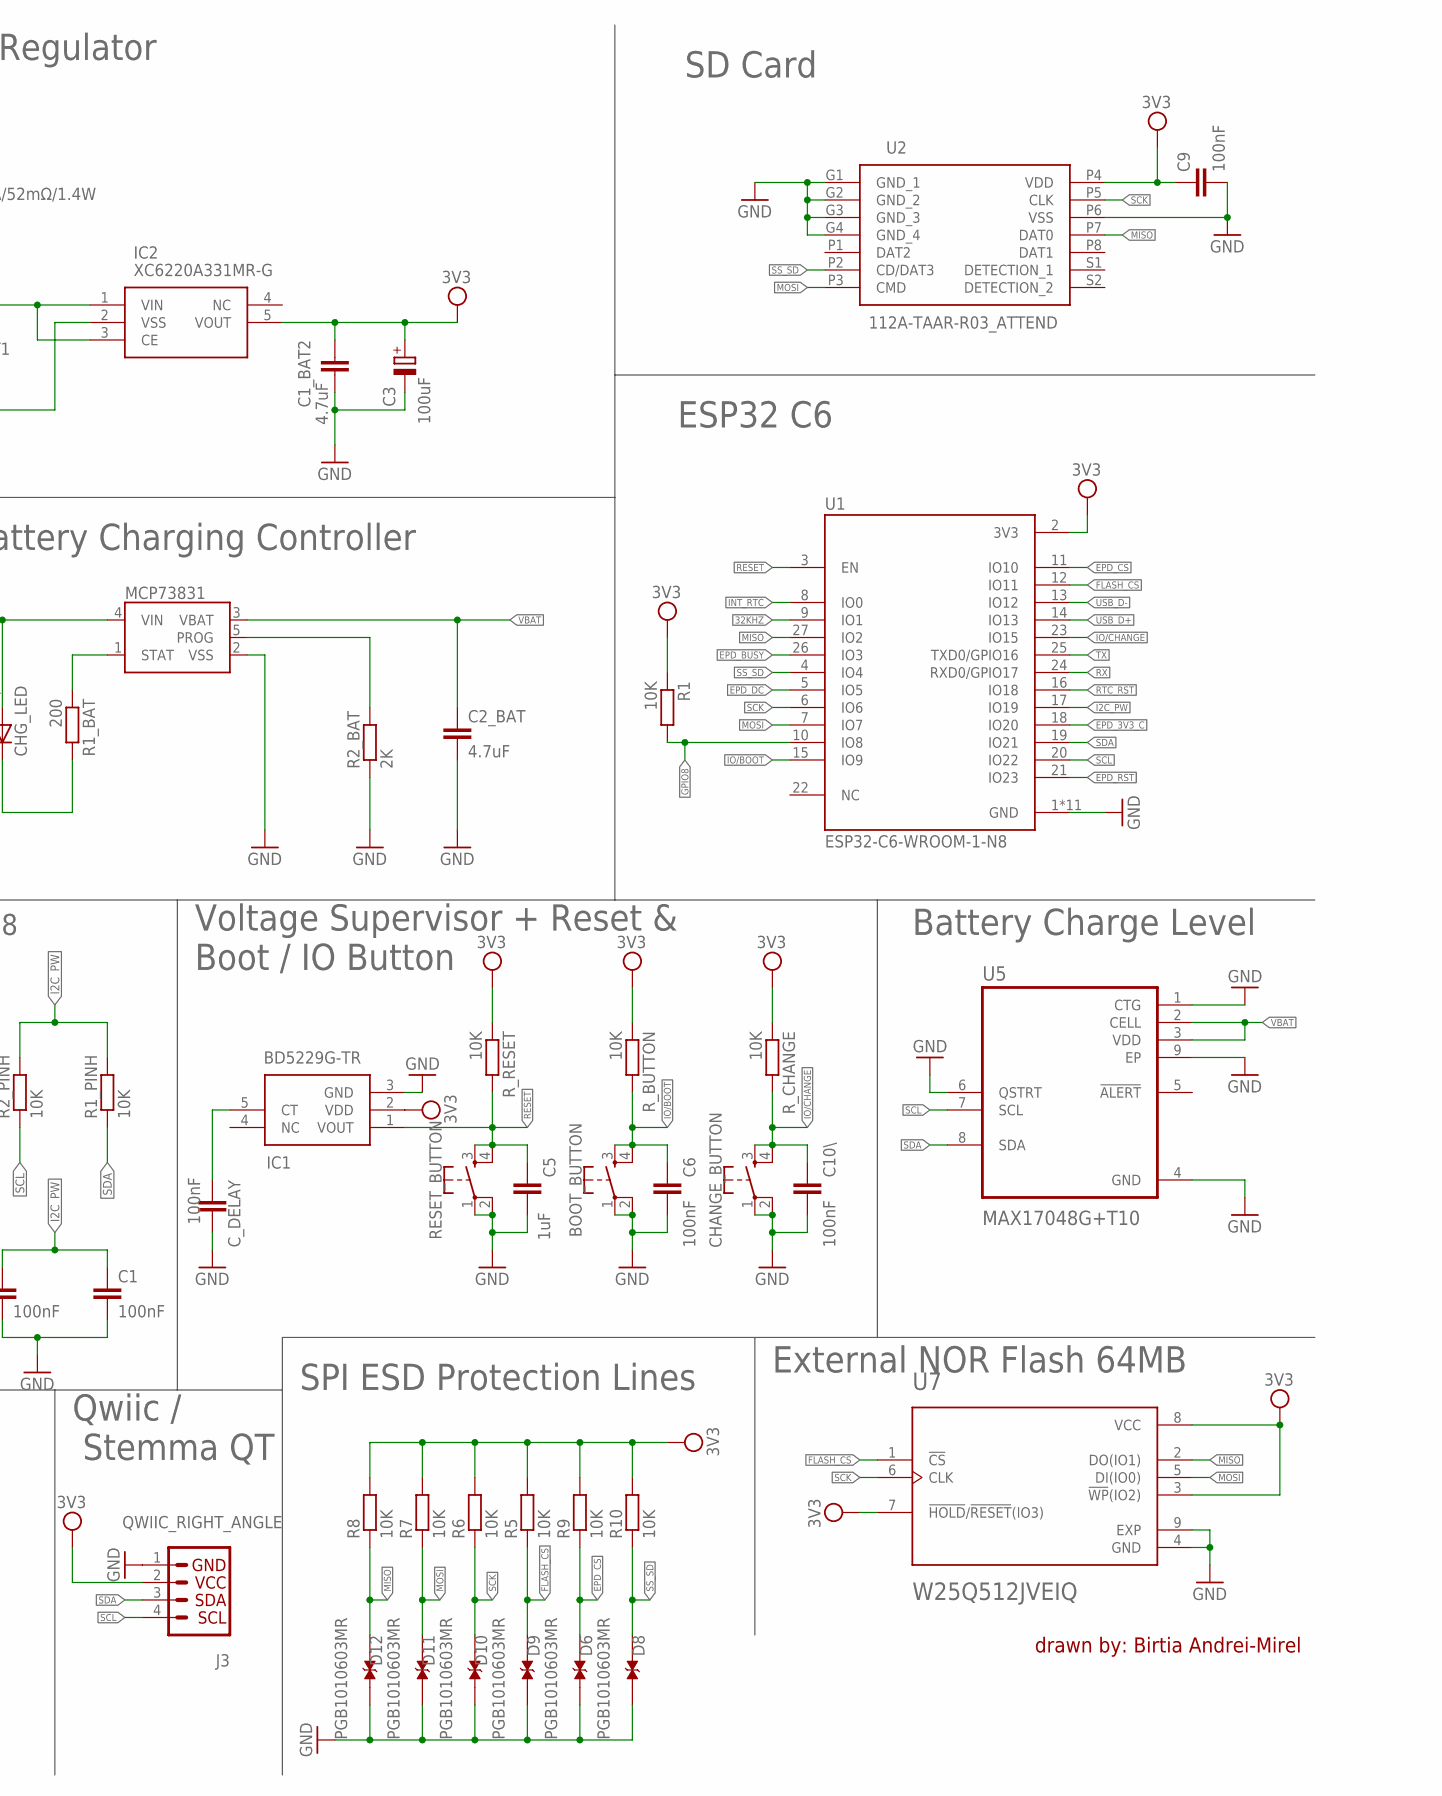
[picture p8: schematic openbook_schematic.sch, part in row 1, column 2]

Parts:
BOOT_BUTTON: BUTTON_CUSYOMV1; MYBUTTON
C1, C2, C4_USB, C6, C8, C9, C10\: 100nF; EAGLE-LTSPICE_C0402
C1_BAT, C1_BAT1, C1_BAT2, C2_BAT, C5_USB: 4.7uF; EAGLE-LTSPICE_C0402
C3: 100uF; RCL_CT3528
C4: 4.7uF/25V; EAGLE-LTSPICE_C0402
C5: 1uF; EAGLE-LTSPICE_C0402
C7: 10uF; EAGLE-LTSPICE_C0402
C10_SUPERCAP: CPH3225A; CAPCP3225X100N
CHANGE_BUTTON: BUTTON_CUSYOMV1; MYBUTTON
CHG_LED: ADAFRUIT_LEDCHIP-LED0603; ADAFRUIT_CHIP-LED0603
C_DELAY: 100nF; EAGLE-LTSPICE_C0402
D1: USBLC6-2SC6Y; SOT95P280X145-6N
D2, D7: ESP32_WROVER_AVX---SD0805S020S1R0_AVX_SD0805S020S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; ESP32_WROVER_AVX---SD0805S020S1R0_AVX_SD0805S020S1R0_0
D3, D4, D5: MBR0530; SOD3716X135N
D6, D8, D9, D10, D11, D12: PGB1010603MR; DIOC1608X36N
EPD_C1, EPD_C2, EPD_C5, EPD_C6, EPD_C7, EPD_C8, EPD_C9, EPD_C10, EPD_C11, EPD_C12: 1uF/50V; EAGLE-LTSPICE_C0402
IC1: BD5229G-TR; SOT95P280X125-5N
IC2: XC6220A331MR-G; SOT95P280X120-5N
J1: FH34SRJ-24S-0.5SH_99_; FH34SRJ24S05SH99
J2: SAMACSYS_PARTS_USB4110-GF-A; SAMACSYS_PARTS_USB4110GFA
J3: QWIIC_RIGHT_ANGLE; JST04_1MM_RA
L1: 744043680IND_4828-WE-TPC_WRE; IND_4828-WE-TPC_WRE
MCP73831: ESP32_WROVER_SPARKFUN-IC-POWER_MCP73831; ESP32_WROVER_SPARKFUN-IC-POWER_SOT23-5
PFMF.050.1: ESP32C6_VARISTORCN1812; ESP32C6_VARISTOR_CT/CN1812
Q1, Q2: 20V/4.2A/52mΩ/1.4W; ESP32_WROVER_SPARKFUN-DISCRETESEMI_SOT23-3
Q3: SI1308EDL-T1-GE3; SOT65P210X110-3N
R1, R1_PINH, R1_PINH1, R2_PINH, R2_PINH1, R5, R6, R7, R8, R9, R10: 10K; ESP32_WROVER_EAGLE-LTSPICE_R0402
R1-USB, R2-USB: 5k1; ESP32_WROVER_EAGLE-LTSPICE_R0402
R1_BAT: 200; ESP32_WROVER_EAGLE-LTSPICE_R0402
R1_PWRUSB: 100k; ESP32_WROVER_EAGLE-LTSPICE_R0402
R2: 2.2; ESP32_WROVER_EAGLE-LTSPICE_R0402
R2_BAT: 2K; ESP32_WROVER_EAGLE-LTSPICE_R0402
R3: 0.47; ESP32_WROVER_EAGLE-LTSPICE_R0402
R4: 10k; ESP32_WROVER_EAGLE-LTSPICE_R0402
RESET_BUTTON: BUTTON_CUSYOMV1; MYBUTTON
R_BUTTON: 10K; ESP32_WROVER_EAGLE-LTSPICE_R0402
R_CAPACITOR: 15; ESP32_WROVER_EAGLE-LTSPICE_R0402
R_CHANGE: 10K; ESP32_WROVER_EAGLE-LTSPICE_R0402
R_CL1: 10K; ESP32_WROVER_EAGLE-LTSPICE_R0402
R_RESET: 10K; ESP32_WROVER_EAGLE-LTSPICE_R0402
SENSOR2: BME688; ESP32_WROVER_BME680_PSON80P300X300X100-8N
SJ1: SJ
TP1, TP2, TP3, TP4, TP5, TP6, TP7, TP8, TP9, TP10, TP11, TP12, TP13, TP14, TP15, TP16, TP17: TPTP20R; TP20R
U1: ESP32-C6-WROOM-1-N8; XCVR_ESP32-C6-WROOM-1-N8
U2: 112A-TAAR-R03_ATTEND; 112ATAARR03ATTEND
U3: DS3231SN#; SOIC127P1032X265-16N
U5: MAX17048G+T10; SON50P200X200X80-9N
U7: W25Q512JVEIQ; SON127P600X800X80-9N

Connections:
3V3: C1_BAT2.1, C3.+, C9.1, D7.2 (ANODE), IC1.2 (VDD), IC2.5 (VOUT), J3.2, Q2.3 (D), R1.1, R1_PINH1.2, R2_PINH1.2, R5.2, R6.2, R7.2, R8.2, R9.2, R10.2, R_BUTTON.1, R_CHANGE.1, R_CL1.1, R_RESET.1, TP16.TP, U1.2 (3V3), U2.P4 (VDD), U3.2 (VCC), U7.3 (!WP!(IO2)), U7.7 (!HOLD!/!RESET!(IO3)), U7.8 (VCC)
32KHZ: R2_PINH1.1, U1.9 (IO1), U3.1 (32KHZ)
DN: D1.4 (I/O2_2), J2.A7, J2.B7
DP: D1.6 (I/O1_2), J2.A6, J2.B6
EPD_3V3: C7.1, EPD_C5.1, J1.15, J1.16, L1.2, Q2.2 (S), TP17.TP
EPD_3V3_C: Q2.1 (G), R_CL1.2, TP3.TP, U1.18 (IO20)
EPD_BUSY: J1.9, TP9.TP, U1.26 (IO3)
EPD_CS: D6.1, J1.12, R9.1, TP10.TP, U1.11 (IO10)
EPD_DC: J1.11, TP1.TP, U1.5 (IO5)
EPD_RST: J1.10, TP2.TP, U1.21 (IO23)
FLASH_CS: D9.1, R5.1, U1.12 (IO11), U7.1 (!CS)
GDR: J1.2, Q3.1 (G), R4.2
GND: BOOT_BUTTON.1, BOOT_BUTTON.2, C1.2, C1_BAT.2, C1_BAT1.2, C1_BAT2.2, C2.2, C2_BAT.2, C3.-, C4_USB.2, C5.2, C5_USB.2, C6.2, C7.2, C8.2, C9.2, C10\.2, C10_SUPERCAP.1, CHANGE_BUTTON.1, CHANGE_BUTTON.2, C_DELAY.2, D1.2 (GND), D3.1 (K), D6.2, D8.2, D9.2, D10.2, D11.2, D12.2, EPD_C1.2, EPD_C2.2, EPD_C5.2, EPD_C6.2, EPD_C7.2, EPD_C8.2, EPD_C9.2, EPD_C10.2, EPD_C11.2, EPD_C12.2, IC1.3 (GND), IC2.2 (VSS), J1.8, J1.17, J1.MP1, J1.MP2, J2.A1, J2.A12, J2.B1, J2.B12, J2.MP1, J2.MP2, J2.MP3, J2.MP4, J3.1, MCP73831.2 (VSS), R1-USB.1, R1_PWRUSB.1, R2.1, R2-USB.2, R2_BAT.1, R4.1, RESET_BUTTON.1, RESET_BUTTON.2, SENSOR2.1 (GND), SENSOR2.5 (SDO), SENSOR2.7 (GND), SJ1.1, TP14.TP, TP15.TP, U1.1 (GND), U1.28 (GND), U1.29_1 (GND), U1.29_2 (GND), U1.29_3 (GND), U1.29_4 (GND), U1.29_5 (GND), U1.29_6 (GND), U1.29_7 (GND), U1.29_8 (GND), U1.29_9 (GND), U2.G1 (GND_1), U2.G2 (GND_2), U2.G3 (GND_3), U2.G4 (GND_4), U2.P6 (VSS), U3.13 (GND), U5.1 (CTG), U5.4 (GND), U5.6 (QSTRT), U5.9 (EP), U7.4 (GND), U7.9 (EXP)
GPIO8: R1.2, U1.10 (IO8)
I2C_PW: C1.1, C2.1, R1_PINH.2, R2_PINH.2, SENSOR2.2 (CSB), SENSOR2.6 (VDDIO), SENSOR2.8 (VDD), U1.17 (IO19)
INT_RTC: R1_PINH1.1, TP5.TP, U1.8 (IO0), U3.3 (SQW/!INT)
IO/BOOT: BOOT_BUTTON.3, BOOT_BUTTON.4, C6.1, R_BUTTON.2, U1.15 (IO9)
IO/CHANGE: C10\.1, CHANGE_BUTTON.3, CHANGE_BUTTON.4, R_CHANGE.2, U1.23 (IO15)
MISO: D12.1, R8.1, TP6.TP, U1.27 (IO2), U2.P7 (DAT0), U7.2 (DO(IO1))
MOSI: D11.1, J1.14, R7.1, TP7.TP, U1.7 (IO7), U2.P3 (CMD), U7.5 (DI(IO0))
unnamed: J2.B5, R2-USB.1
unnamed: J2.A5, R1-USB.2
unnamed: MCP73831.5 (PROG), R2_BAT.2
unnamed: EPD_C2.1, J1.5
unnamed: C1_BAT1.1, D2.1 (CATHODE), IC2.1 (VIN), IC2.3 (CE), Q1.2 (S)
unnamed: MCP73831.1 (STAT), R1_BAT.1
unnamed: C4.1, D3.2 (A), D4.1 (K)
unnamed: CHG_LED.C, R1_BAT.2
unnamed: EPD_C1.1, J1.4
unnamed: EPD_C12.1, J1.24
unnamed: C_DELAY.1, IC1.5 (CT)
unnamed: EPD_C10.1, J1.22
unnamed: D7.1 (CATHODE), R_CAPACITOR.1
unnamed: EPD_C8.1, J1.20
unnamed: EPD_C7.1, J1.19
unnamed: EPD_C6.1, J1.18
PREVGH: D5.1 (K), EPD_C9.1, J1.21
PREVGL: D4.2 (A), EPD_C11.1, J1.23
RESE: J1.3, Q3.2 (S), R3.2
RESE': R2.2, R3.1, SJ1.2
RESET: C5.1, IC1.1 (VOUT), RESET_BUTTON.3, RESET_BUTTON.4, R_RESET.2, U1.3 (EN)
RTC_RST: U1.16 (IO18), U3.4 (!RST)
RX: TP12.TP, U1.24 (RXD0/GPIO17)
SCK: D10.1, J1.13, R6.1, TP8.TP, U1.6 (IO6), U2.P5 (CLK), U7.6 (CLK)
SCL: J3.4, R2_PINH.1, SENSOR2.4 (SCK), U1.20 (IO22), U3.16 (SCL), U5.7 (SCL)
SDA: J3.3, R1_PINH.1, SENSOR2.3 (SDI), U1.19 (IO21), U3.15 (SDA), U5.8 (SDA)
SRC: C4.2, D5.2 (A), L1.1, Q3.3 (D)
SS_SD: D8.1, R10.1, U1.4 (IO4), U2.P2 (CD/DAT3)
TX: TP11.TP, U1.25 (TXD0/GPIO16)
USB_D+: D1.1 (I/O1_1), U1.14 (IO13)
USB_D-: D1.3 (I/O2_1), U1.13 (IO12)
VBAT: C2_BAT.1, D2.2 (ANODE), MCP73831.3 (VBAT), Q1.1 (G), Q1.3 (D), R1_PWRUSB.2, TP13.TP, U5.2 (CELL), U5.3 (VDD)
VBUS: C1_BAT.1, C4_USB.1, C5_USB.1, CHG_LED.A, D1.5 (VBUS), MCP73831.4 (VIN), TP4.TP
VRTC: C8.1, C10_SUPERCAP.2, R_CAPACITOR.2, U3.14 (VBAT)
VUSB: J2.A4, J2.A9, J2.B4, J2.B9, PFMF.050.1.1, PFMF.050.1.2

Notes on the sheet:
USB C connector & ESD protection
LDO Voltage Regulator
SD Card
ESP32 C6
Li-Po Battery Charging Controller
E-Paper Drive Circuit
Display Type Selector
E-Paper Display Header
EPD Power
Environmental Sensor BME688
Voltage Supervisor + Reset & Boot / IO Button
Battery Charge Level
External NOR Flash 64MB
SPI ESD Protection Lines
Qwiic / Stemma QT
Test Pads
RTC Module DS3231SN
drawn by: Birtia Andrei-Mirel

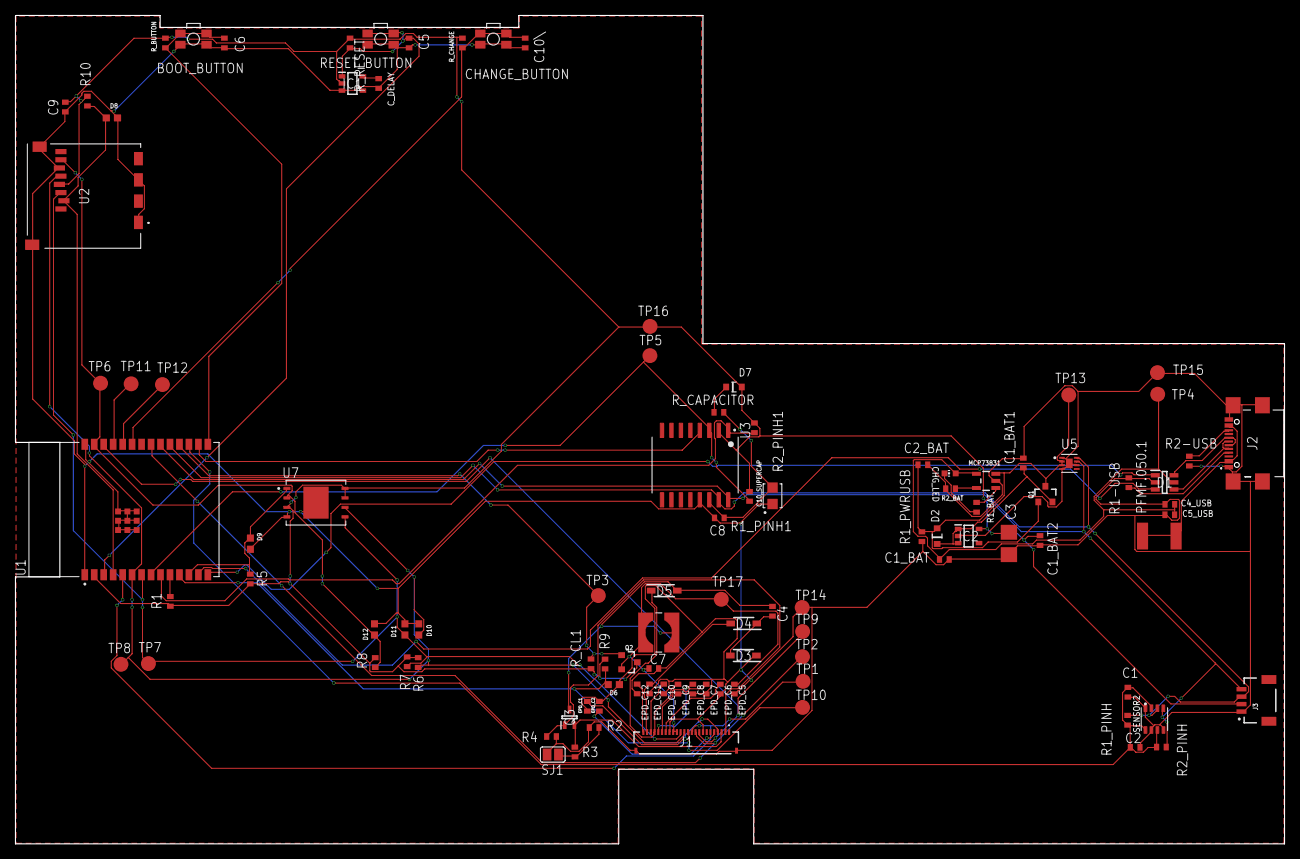
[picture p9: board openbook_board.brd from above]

Board: 2 copper layers, 170.2 x 111.1 mm, 103 parts (0 on the bottom side), 55 nets.

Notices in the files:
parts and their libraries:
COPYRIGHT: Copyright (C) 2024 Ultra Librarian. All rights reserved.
